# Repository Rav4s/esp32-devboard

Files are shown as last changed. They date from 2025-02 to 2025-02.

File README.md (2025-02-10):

# esp32-devboard
Development board for the ESP32 :P

TODO: all other notes...

## BOM
IBOM: BOM/ibom.html (download and view in browser)  
Mouser Cart: https://www.mouser.com/ProjectManager/ProjectDetail.aspx?AccessID=de87a8ab7b

## Ideas
key ring size, button, leds, how to pwr??, thread/matter for smth? cool enclosure..., NFC, ENIG
board should be dragon shaped heheh or smth else scary LED EYES ORANGE

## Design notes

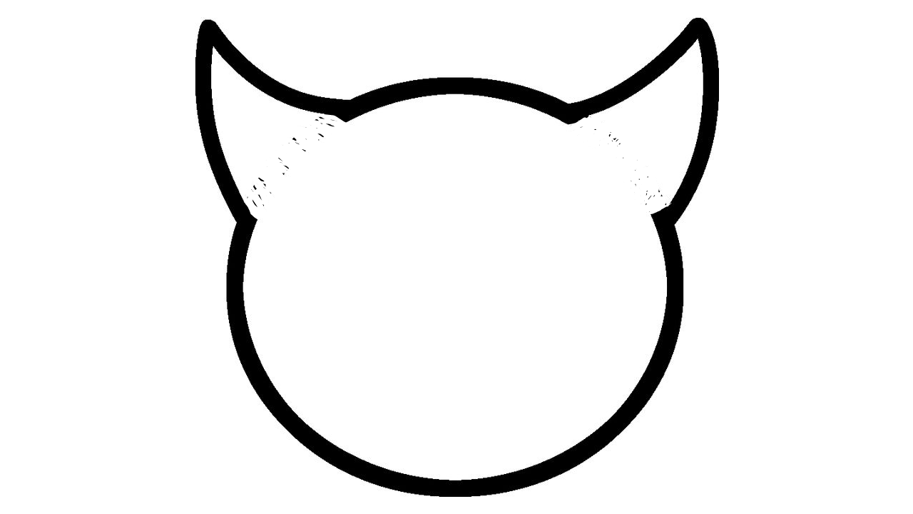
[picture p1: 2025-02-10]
Custom-KiCadLibraries/Outline/board outline.png

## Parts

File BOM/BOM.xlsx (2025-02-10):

Reference | Value | Qty | P/N
C1,C2,C4,C9 | 10u | 4 | MLAST168BB5106MTNA01
C3,C5,C6,C7,C10,C11,C12 | 0.1u | 7 | UMK107B7104KAHT
C8 | 1u | 1 | C0603X105J4RAC7411
D1 | 1N5819HW-7-F | 1 | 1N5819HW-7-F
D2,D3,D4 | TVS | 3 | CPDUC5V0R-HF
D5,D6,D7 | -- mixed values -- | 3 | HSML-C191
J1 | USB_C_Receptacle_USB2.0_16P | 1 | 640-USB4215-03-A
J2 | CA | 1 | 54101-S0802LF
J3 | CB | 1 | 54101-S0803LF
R1,R2 | 5.1k | 2 | CRCW06035K10FKEC
R3,R7,R10 | 47 | 3 | MCT06030C4709FP500
R4,R5,R9 | 10k | 3 | MCT0603PD1002DP500
R6 | 3.3k | 1 | ERA-3APB332V
R8 | 10k | 1 | MCT0603PD1002DP500
SW1,SW2,SW3,SW4 | -- mixed values -- | 4 | KMR231GLFS
TP2,TP3 | -- mixed values -- | 2
U1 | ESP32-C6-MINI-1/U | 1 | ESP32-C6-MINI-1/U
U2 | AMS1117-3.3 | 1 | AMS1117-3.3

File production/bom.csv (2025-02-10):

Designator | Footprint | Quantity | Value | LCSC Part #
C1, C2, C4, C9 | 0603 | 4 | 10u
C10, C11, C12, C3, C5, C6, C7 | 0603 | 7 | 0.1u
C8 | 0603 | 1 | 1u
D1 | D_SOD-123 | 1 | 1N5819HW-7-F
D2, D3, D4 | 0603 | 3 | TVS
D5, D6 | 0603 | 2 | PWR
D7 | 0603 | 1 | DANGER
J1 | USB_C_Receptacle_GCT_USB4105-xx-A_16P_TopMnt_Horizontal | 1 | USB_C_Receptacle_USB2.0_16P
J2 | PinHeader_1x02_P2.54mm_Vertical | 1 | CA
J3 | PinHeader_1x03_P2.54mm_Vertical | 1 | CB
R1, R2 | 0603 | 2 | 5.1k
R10, R3, R7 | 0603 | 3 | 47
R4, R5, R8, R9 | 0603 | 4 | 10k
R6 | 0603 | 1 | 3.3k
SW1 | SW_Push_1P1T_NO_CK_KMR2 | 1 | BOOT
SW2 | SW_Push_1P1T_NO_CK_KMR2 | 1 | RST
SW3 | SW_Push_1P1T_NO_CK_KMR2 | 1 | FLIP
SW4 | SW_Push_1P1T_NO_CK_KMR2 | 1 | FLOP
TP2 | TestPoint_Pad_D1.0mm | 1 | 3.3V
TP3 | TestPoint_Pad_D1.0mm | 1 | GND
U1 | ESP32-C6-MINI-1 | 1 | ESP32-C6-MINI-1/U
U2 | SOT-223-3_TabPin2 | 1 | AMS1117-3.3

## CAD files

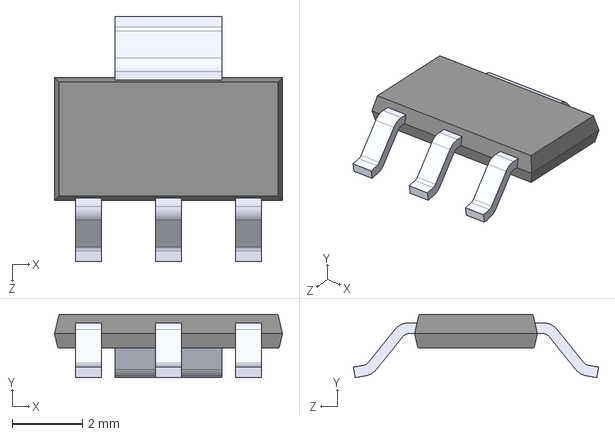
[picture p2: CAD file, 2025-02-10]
Custom-KiCadLibraries/AMS1117-3.3/AMS1117-3.3.step
6.50 x 1.80 x 7.00 mm

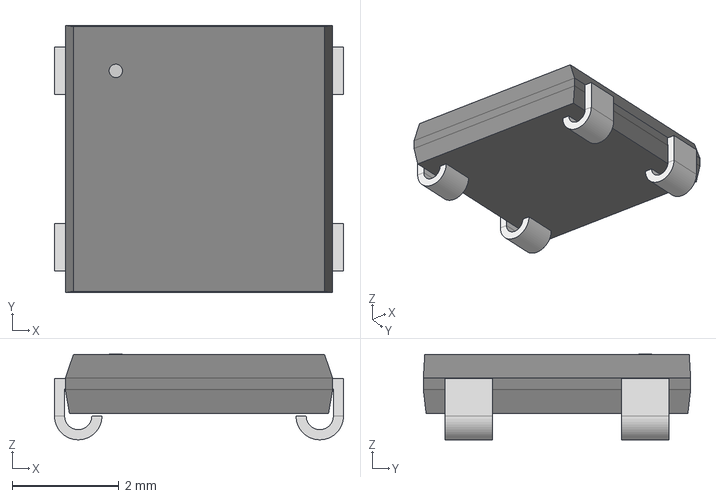
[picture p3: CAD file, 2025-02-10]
Custom-KiCadLibraries/COM-16347/COM-16347_SPK.step
5.41 x 5.00 x 1.60 mm

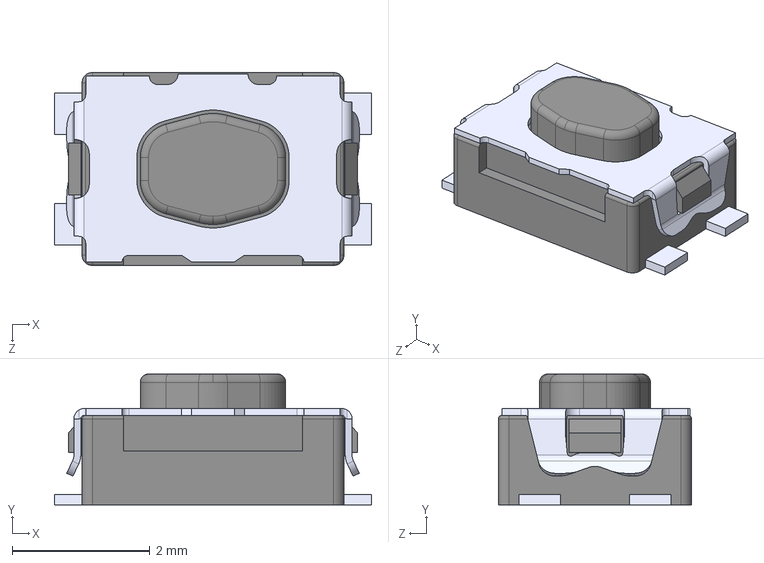
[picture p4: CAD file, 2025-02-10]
Custom-KiCadLibraries/KMR231GLFS/KMR231NGLFS--3DModel-STEP-56544.STEP
4.60 x 1.90 x 2.80 mm

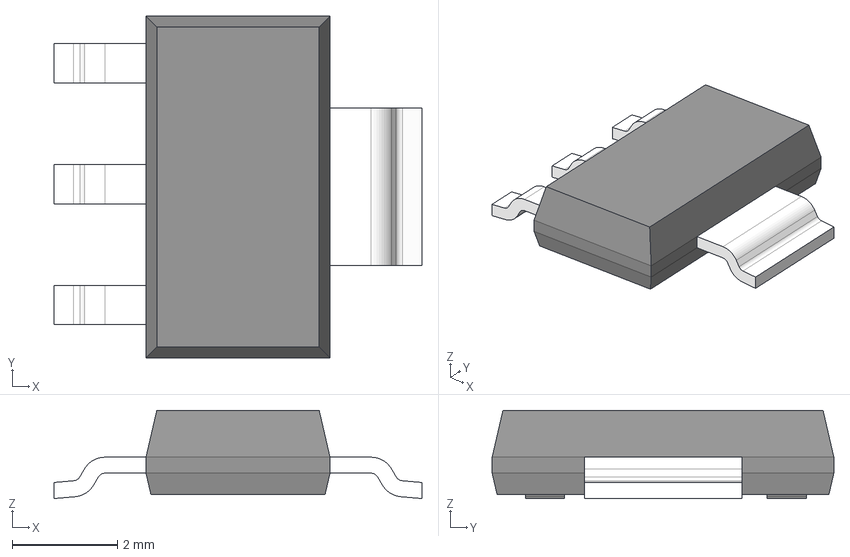
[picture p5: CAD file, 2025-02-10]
Custom-KiCadLibraries/LM3940IMP/DCY0004A.stp
7.00 x 6.50 x 1.68 mm
BODY-SOT
LEAD-SOT x 3
LEAD-SOT-WIDE
PIN1-ID

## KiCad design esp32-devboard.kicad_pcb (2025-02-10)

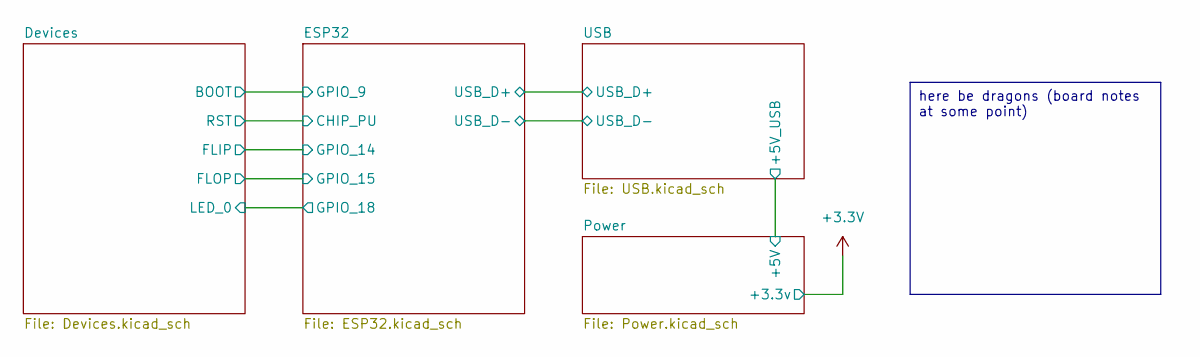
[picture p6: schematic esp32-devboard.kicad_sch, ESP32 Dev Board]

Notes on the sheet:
here be dragons (board notes at some point)

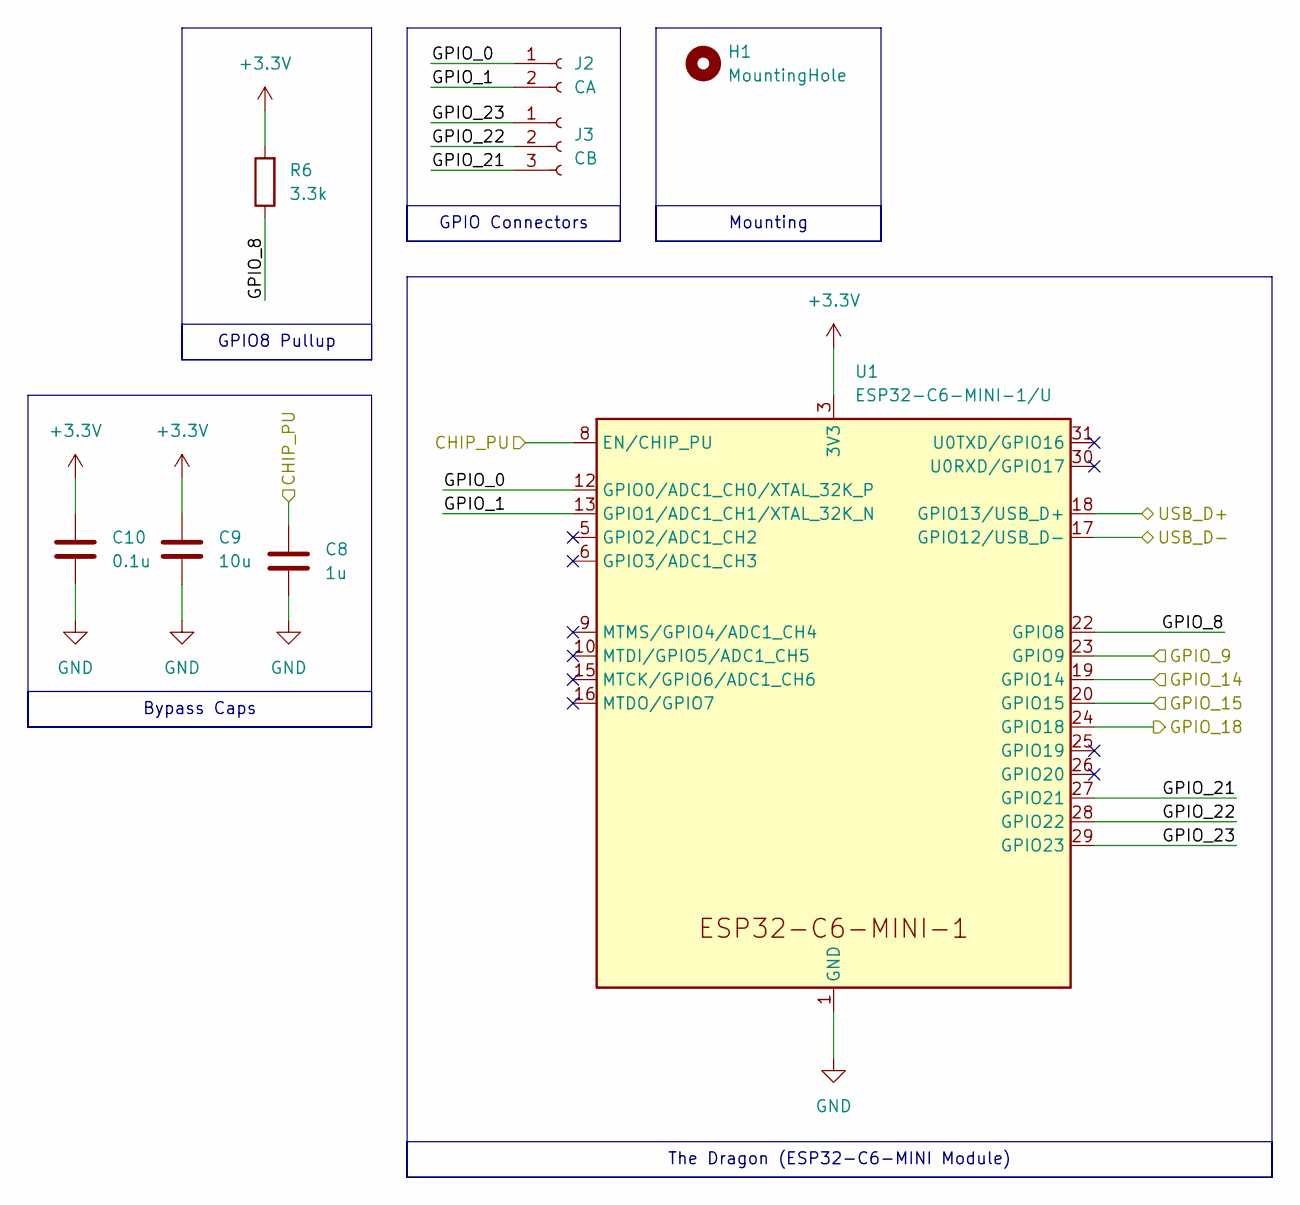
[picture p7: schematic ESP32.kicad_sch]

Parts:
C8: 1u; C_0603_1608Metric
C9: 10u; C_0603_1608Metric
C10: 0.1u; C_0603_1608Metric
H1: MountingHole; MountingHole_2.2mm_M2
J2: CA; PinHeader_1x02_P2.54mm_Vertical
J3: CB; PinHeader_1x03_P2.54mm_Vertical
R6: 3.3k; R_0603_1608Metric
U1: ESP32-C6-MINI-1/U; ESP32-C6-MINI-1

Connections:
+3.3V: C9.1, C10.1, R6.2, U1.3 (3V3); also elsewhere on the board
/Devices/BOOT: U1.23 (GPIO9); also elsewhere on the board
/Devices/FLIP: U1.19 (GPIO14); also elsewhere on the board
/Devices/FLOP: U1.20 (GPIO15); also elsewhere on the board
/Devices/LED_0: U1.24 (GPIO18); also elsewhere on the board
/Devices/RST: C8.1, U1.8 (EN/CHIP_PU); also elsewhere on the board
/ESP32/GPIO_0: J2.1, U1.12 (GPIO0/ADC1_CH0/XTAL_32K_P)
/ESP32/GPIO_1: J2.2, U1.13 (GPIO1/ADC1_CH1/XTAL_32K_N)
/ESP32/GPIO_8: R6.1, U1.22 (GPIO8)
/ESP32/GPIO_21: J3.3, U1.27 (GPIO21)
/ESP32/GPIO_22: J3.2, U1.28 (GPIO22)
/ESP32/GPIO_23: J3.1, U1.29 (GPIO23)
/ESP32/USB_D+: U1.18 (GPIO13/USB_D+); also elsewhere on the board
/ESP32/USB_D-: U1.17 (GPIO12/USB_D-); also elsewhere on the board
GND: C8.2, C9.2, C10.2, U1.1 (GND), U1.2 (GND), U1.11 (GND), U1.14 (GND), U1.36 (GND), U1.37 (GND), U1.38 (GND), U1.39 (GND), U1.40 (GND), U1.41 (GND), U1.42 (GND), U1.43 (GND), U1.44 (GND), U1.45 (GND), U1.46 (GND), U1.47 (GND), U1.48 (GND), U1.49 (GND), U1.50 (GND), U1.51 (GND), U1.52 (GND), U1.53 (GND); also elsewhere on the board

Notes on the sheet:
GPIO8 Pullup
Bypass Caps
GPIO Connectors
The Dragon (ESP32-C6-MINI Module)
Mounting

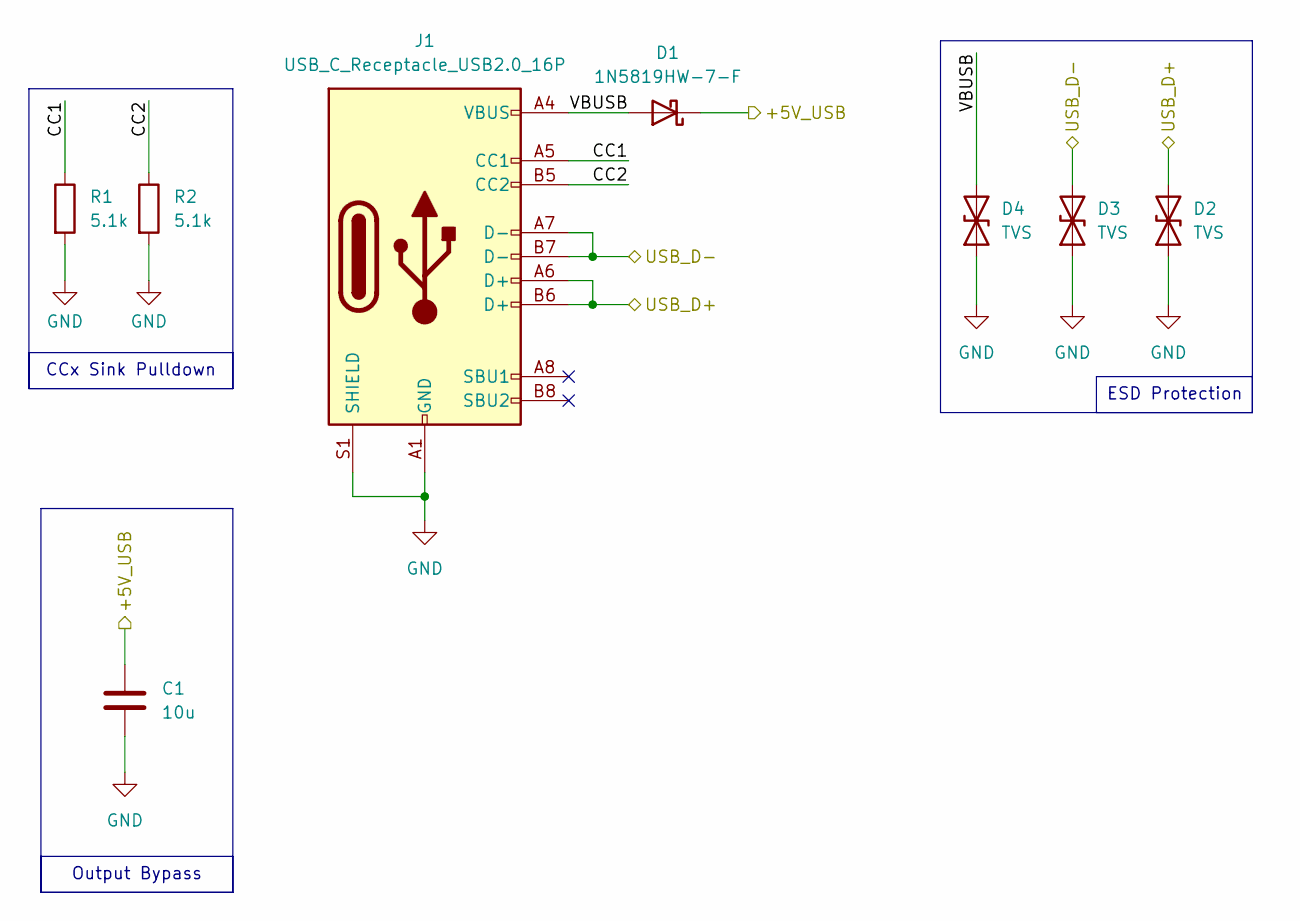
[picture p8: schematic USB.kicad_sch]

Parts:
C1: 10u; C_0603_1608Metric
D1: 1N5819HW-7-F; D_SOD-123
D2, D3, D4: TVS; D_0603_1608Metric
J1: USB_C_Receptacle_USB2.0_16P; USB_C_Receptacle_GCT_USB4105-xx-A_16P_TopMnt_Horizontal
R1, R2: 5.1k; R_0603_1608Metric

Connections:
/ESP32/USB_D+: D2.2 (A2), J1.A6 (D+), J1.B6 (D+); also elsewhere on the board
/ESP32/USB_D-: D3.2 (A2), J1.A7 (D-), J1.B7 (D-); also elsewhere on the board
/Power/+5V: C1.1, D1.1 (K); also elsewhere on the board
/USB/CC1: J1.A5 (CC1), R1.1
/USB/CC2: J1.B5 (CC2), R2.1
/USB/VBUSB: D1.2 (A), D4.2 (A2), J1.A4 (VBUS), J1.A9 (VBUS), J1.B4 (VBUS), J1.B9 (VBUS)
GND: C1.2, D2.1 (A1), D3.1 (A1), D4.1 (A1), J1.A1 (GND), J1.A12 (GND), J1.B1 (GND), J1.B12 (GND), J1.S1 (SHIELD), R1.2, R2.2; also elsewhere on the board

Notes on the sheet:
Output Bypass
ESD Protection
CCx Sink Pulldown

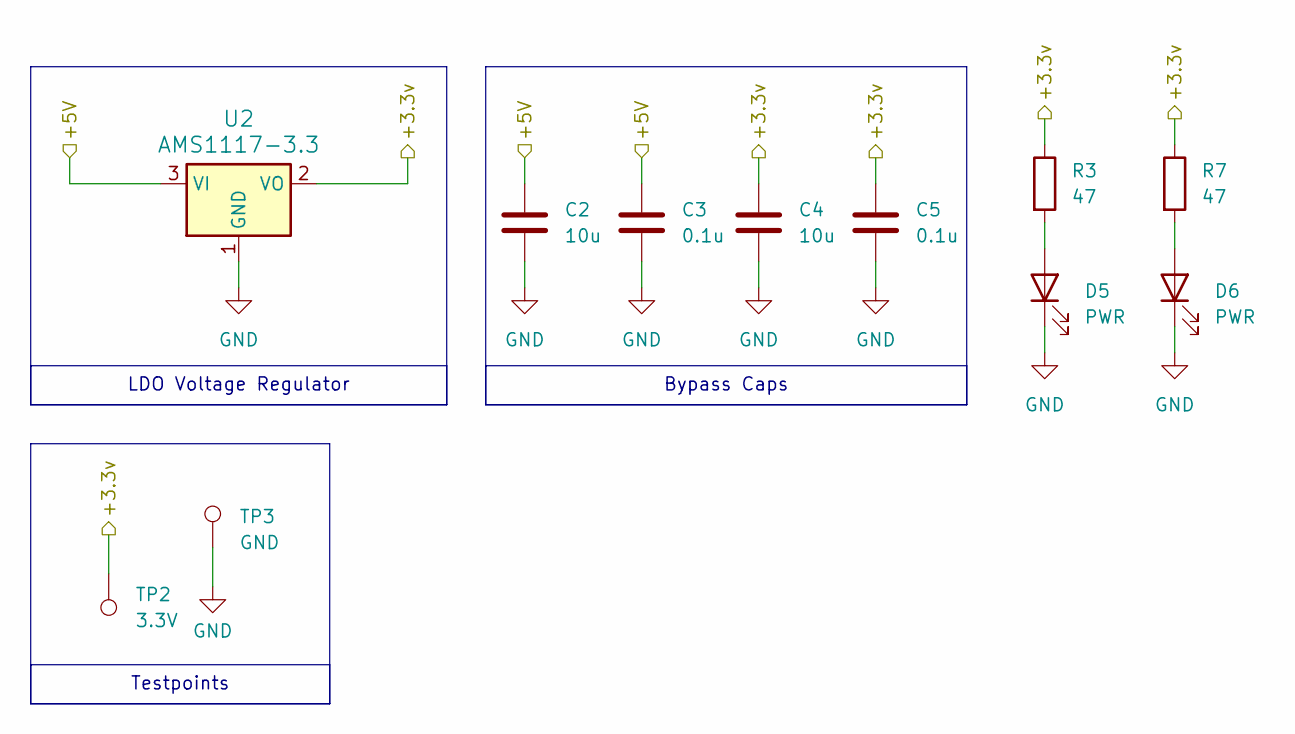
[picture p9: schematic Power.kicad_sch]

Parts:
C2, C4: 10u; C_0603_1608Metric
C3, C5: 0.1u; C_0603_1608Metric
D5, D6: PWR; LED_0603_1608Metric
R3, R7: 47; R_0603_1608Metric
TP2: 3.3V; TestPoint_Pad_D1.0mm
TP3: GND; TestPoint_Pad_D1.0mm
U2: AMS1117-3.3; SOT-223-3_TabPin2

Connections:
+3.3V: C4.1, C5.1, R3.1, R7.1, TP2.1, U2.2 (VO); also elsewhere on the board
/Power/+5V: C2.1, C3.1, U2.3 (VI); also elsewhere on the board
GND: C2.2, C3.2, C4.2, C5.2, D5.1 (K), D6.1 (K), TP3.1, U2.1 (GND); also elsewhere on the board
unnamed: D5.2 (A), R3.2
unnamed: D6.2 (A), R7.2

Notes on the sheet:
Testpoints
Bypass Caps
LDO Voltage Regulator

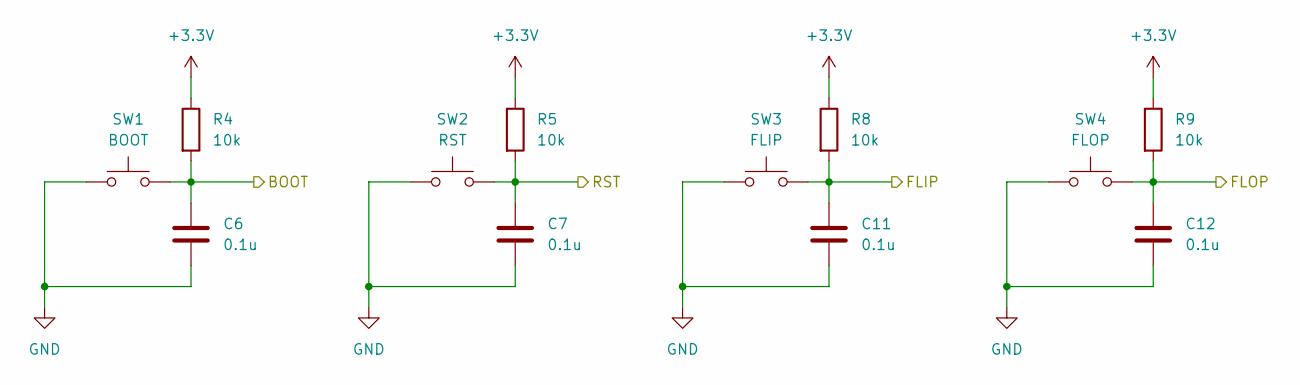
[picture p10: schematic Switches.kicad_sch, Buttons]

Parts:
C6, C7, C11, C12: 0.1u; C_0603_1608Metric
R4, R5, R8, R9: 10k; R_0603_1608Metric
SW1: BOOT; SW_Push_1P1T_NO_CK_KMR2
SW2: RST; SW_Push_1P1T_NO_CK_KMR2
SW3: FLIP; SW_Push_1P1T_NO_CK_KMR2
SW4: FLOP; SW_Push_1P1T_NO_CK_KMR2

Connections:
+3.3V: R4.1, R5.1, R8.1, R9.1; also elsewhere on the board
/Devices/BOOT: C6.1, R4.2, SW1.2; also elsewhere on the board
/Devices/FLIP: C11.1, R8.2, SW3.2; also elsewhere on the board
/Devices/FLOP: C12.1, R9.2, SW4.2; also elsewhere on the board
/Devices/RST: C7.1, R5.2, SW2.2; also elsewhere on the board
GND: C6.2, C7.2, C11.2, C12.2, SW1.1, SW2.1, SW3.1, SW4.1; also elsewhere on the board

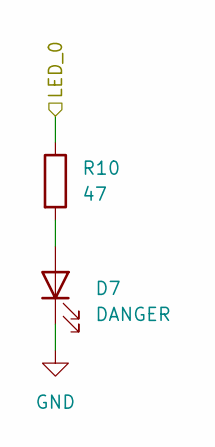
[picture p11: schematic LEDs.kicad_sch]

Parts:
D7: DANGER; LED_0603_1608Metric
R10: 47; R_0603_1608Metric

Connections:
/Devices/LED_0: R10.1; also elsewhere on the board
GND: D7.1 (K); also elsewhere on the board
unnamed: D7.2 (A), R10.2

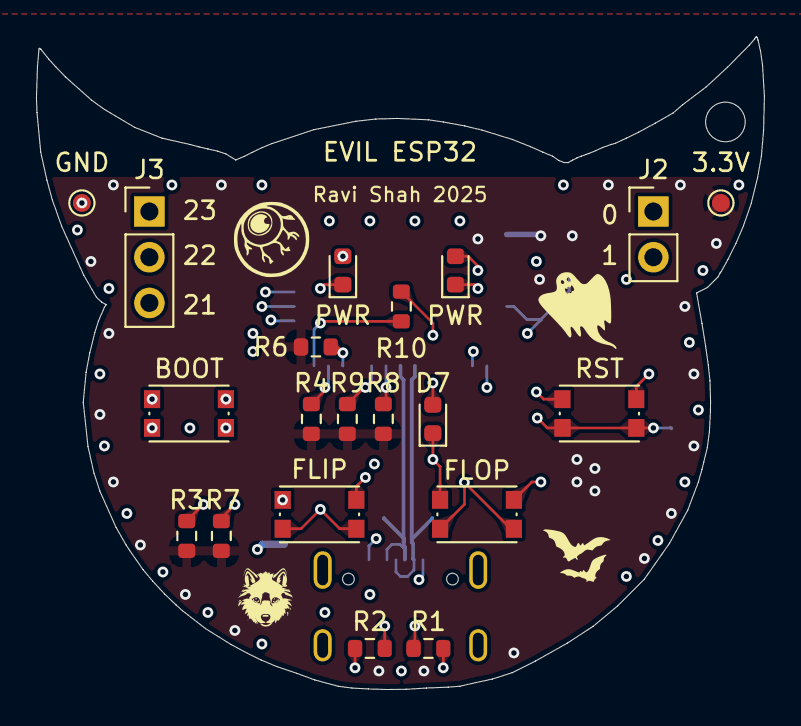
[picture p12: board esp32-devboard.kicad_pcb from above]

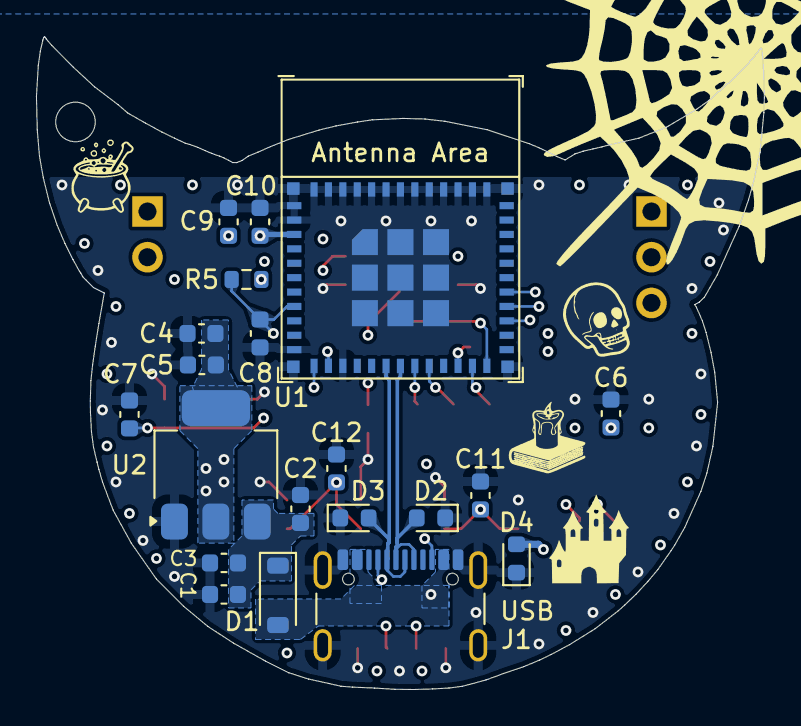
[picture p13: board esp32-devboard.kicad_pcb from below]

Board: 4 copper layers, 40.4 x 36.3 mm, 41 parts (20 on the bottom side), 22 nets.

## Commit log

2025-02-02 add initial file structure
    [Buttons.kicad_sch, Buzzer.kicad_sch, Devices.kicad_sch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]
2025-02-02 added USB-C connector
    [Buttons.kicad_sch, Devices.kicad_sch, ESP32.kicad_sch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]
2025-02-05 USB and PWR sch
    [Buttons.kicad_sch, Buzzer.kicad_sch, DCY0004A.stp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]
2025-02-05 add BOOT/RST switches
    [Devices.kicad_sch, ESP32.kicad_sch, Switches.kicad_sch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]
2025-02-05 finished sch? (need P/Ns)
    [COM-16347_SPK.step, Devices.kicad_sch, ESP32.kicad_sch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]
2025-02-05 add P/N
    [AMS1117-3.3.step, ESP32.kicad_sch, LEDs.kicad_sch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]
2025-02-06 assign footprints
    [ESP32.kicad_sch, LEDs.kicad_sch, Power.kicad_sch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]
2025-02-06 add testpoints
    [Power.kicad_sch, esp32-devboard.kicad_pcb]
2025-02-06 LDO layout>
    [Power.kicad_sch, esp32-devboard.kicad_pcb]
2025-02-06 more pwr stuff
    [esp32-devboard.kicad_pcb]
2025-02-07 more layout & custom edge cuts
    [KMR231NGLFS--3DModel-STEP-56544.STEP, esp32-devboard.kicad_pcb]
2025-02-07 zone fills & button layout
    [esp32-devboard.kicad_pcb]
2025-02-07 more layout (dont look at this)
    [esp32-devboard.kicad_pcb]
2025-02-07 almost done with layout
    [esp32-devboard.kicad_pcb]
2025-02-07 layout kinda done
    [Power.kicad_sch, esp32-devboard.kicad_pcb]
2025-02-07 USB routing
    [esp32-devboard.kicad_pcb]
2025-02-07 initial routing
    [bom.csv, designators.csv, esp32-devboard.kicad_pcb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]
2025-02-08 stupid dumb drc
    [esp32-devboard.kicad_pcb]
2025-02-09 add BOM
    [BOM.xlsx, esp32-devboard.kicad_pcb]
2025-02-09 readme, mounting holes, minor silk changes
    [ESP32.kicad_sch, esp32-devboard.kicad_pcb]
2025-02-09 add cool silkscreen
    [esp32-devboard.kicad_pcb]
2025-02-09 regenerate gerbers
    [designators.csv, positions.csv]
2025-02-10 switch caps for lower cost
    [BOM.xlsx, ESP32.kicad_sch, Power.kicad_sch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]
